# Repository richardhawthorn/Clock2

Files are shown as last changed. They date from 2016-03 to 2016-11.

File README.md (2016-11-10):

### Description

PCB and Arduino code for a basic clock

### Features

- 4 character 7-segment LED display
- ATMEGA328P with Arduino boot-loader
- 5V operation @ 16Mhz
- DS1307 battery backed clock
- 2x buttons to update minutes and seconds
- Mini USB power connector
- FTDI programming port
- Completely through hole design

### License

This work is licensed under a Creative Commons Attribution-ShareAlike 4.0 International License.

<br />
Designed by <a xmlns:cc="http://creativecommons.org/ns#" href="http://www.richardhawthorn.com" property="cc:attributionName" rel="cc:attributionURL" target="_blank">Richard Hawthorn</a><br />
<a rel="license" href="http://creativecommons.org/licenses/by-sa/4.0/" target="_blank">View License</a>

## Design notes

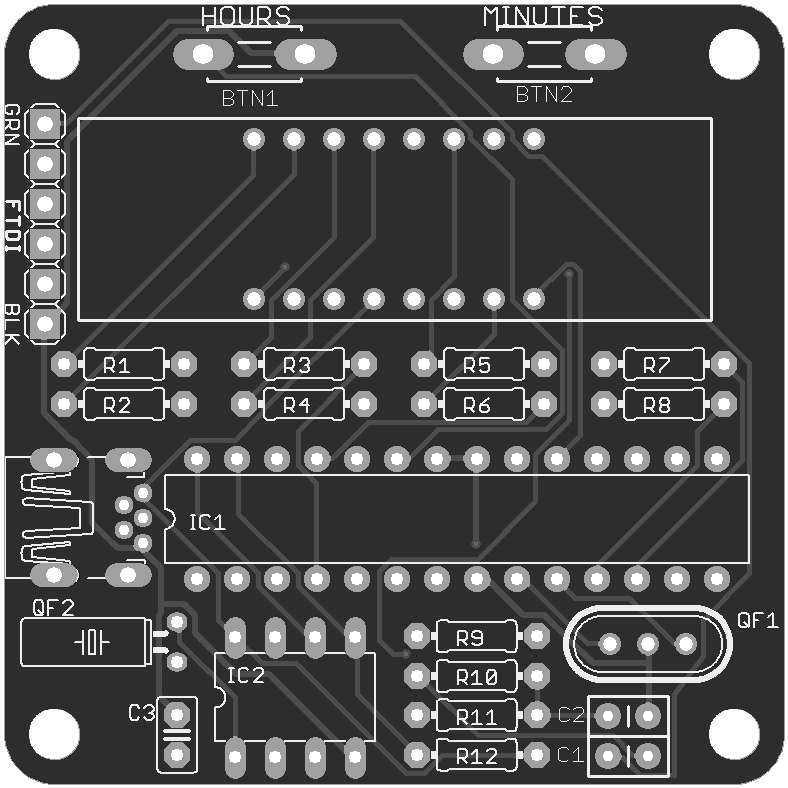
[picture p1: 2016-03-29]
images/pcb_front.png

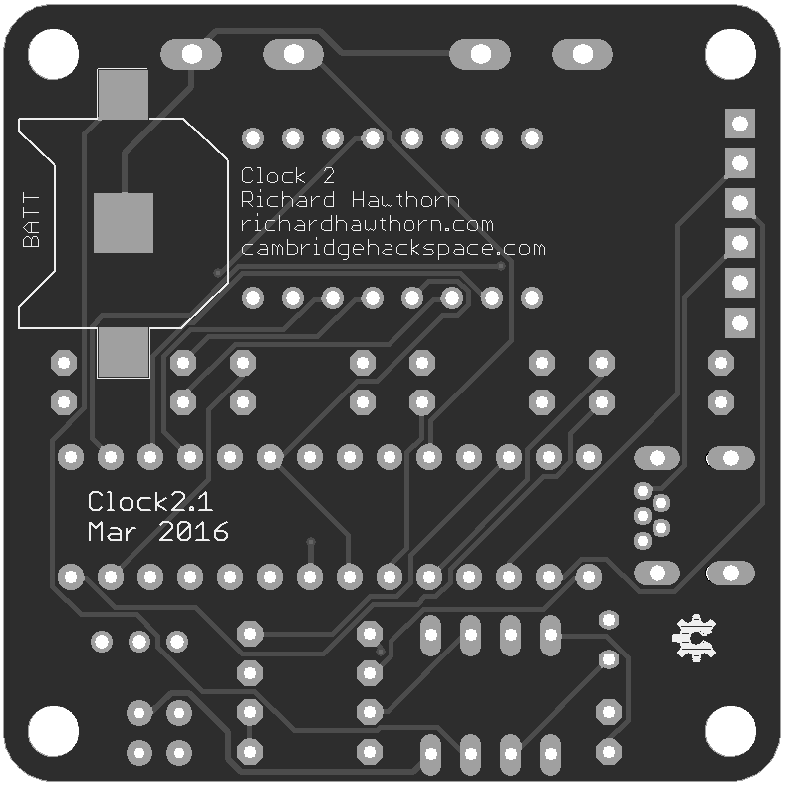
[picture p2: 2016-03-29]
images/pcb_back.png

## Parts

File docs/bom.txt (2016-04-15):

Qty Value       Device                       Package                   Parts                              Description                                    
2   0.1uf       CAP                          CAP-PTH-SMALL             C1, C2, C3                         Capacitor                                                                                                         
3   10K         Resistor                     0204/7                    R10, R11, R12                      Resistor                                                
1   32.768      CRYTALTC38H                  TC38H                     QF2                                Crystal                                                                   
1   7SEG-4DIGIT 7SEG-4DIGIT                  7-SEGMENT-4DIGIT          LED1                               7 Segment LED                                                                          
9   82r         Resistor                     0204/7                    R1, R2, R3, R4, R5, R6, R7, R8, R9 Resistor                                               
1   16Mhz	 16Mhz Crystal                HC49U                     QF1                                Crystal                      
1   ATMEGA328P  ATMEGA328P                   DIL28-3-ROUND             IC1                                Microcontroller                                                           
1   CR1220      CR1220SMT                    CR1220-SMD                BATT                               Battery clip                            
1   DS1307      DS1307                       DIL08                     IC2                                Calendar                                                                    
1   FTDI        PINHD-1X6                    1X06                      CN4                                Pin Header                                                                
1   HOURS       DTS-3                        DTS-3                     BTN1                               Button                                                                          
1   MINUTES     DTS-3                        DTS-3                     BTN2                               Button                                                                          
1   USB         MINI-USB		       32005-601                 X1                                 USB socket

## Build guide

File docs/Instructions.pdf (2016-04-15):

Cambridge Hackspace

# Arduino Clock Assembly Instructions

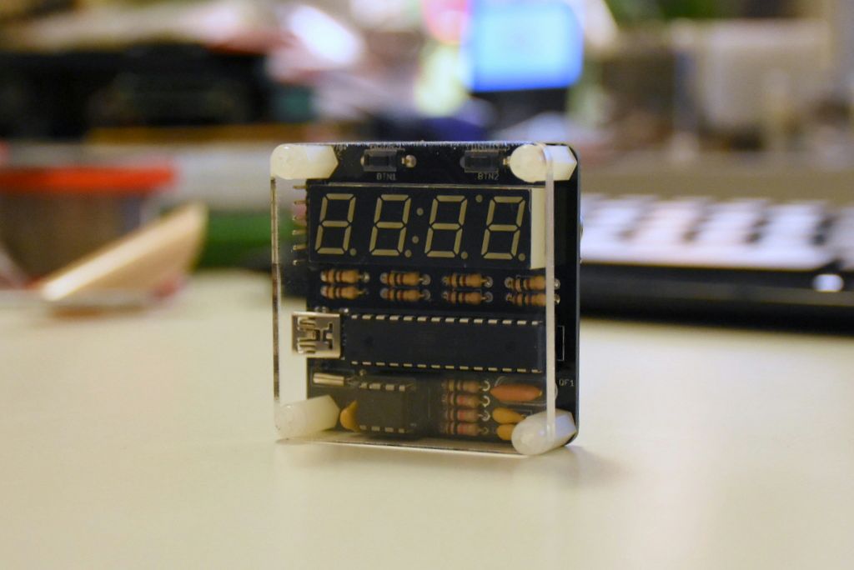
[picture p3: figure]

## Specifications

- 4 character 7-segment LED display
- ATMEGA328P with Arduino boot-loader
- 5V operation @ 16Mhz
- DS1307 battery backed clock
- 2x buttons to update minutes and seconds
- Mini USB power connector
- FTDI programming port

Cambridge Hackspace - Clock2.1

## Parts List

Part # | Qty | Value | Device | Parts
1 | 9 | 82r | Resistor | R1, R2, R3, R4, R5, R6, R7, R8, R9
2 | 3 | 10K | Resistor | R10, R11, R12
3 | 3 | 0.1uf | Capacitor | C1, C2, C3
4 | 1 | DIL28 | 28 pin IC socket | IC1
5 | 1 | ATMEGA328P | Processor | IC1
6 | 1 | DIL8 | 8 pin IC socket | IC2
7 | 1 | DS1307 | Calendar chip | IC2
8 | 1 | 16Mhz | Processor crystal | QF1
9 | 1 | 32.768khz | Calendar crystal | QF2
10 | 1 | 7SEG-4DIGIT | 7 segment LED | LED1
11 | 1 | CR1220 | Battery clip | BATT
12 | 1 | CR1220 | 3V battery | BATT
13 | 1 | USB | Mini USB socket | X1
14 | 1 | FTDI | Pin header | CN4
15 | 1 | HOURS | Button | BTN1
16 | 1 | MINUTES | Button | BTN2
17 | 1 | n/a | PCB | Clock2.1
18 | 1 | n/a | Acrylic front plate | n/a
19 | 4 | n/a | Acrylic pillars | n/a
20 | 8 | n/a | Acrylic screws | n/a
21 | 1 | n/a | Mini USB cable | n/a

## Parts

The kit is supplied with everything you will need to make your Arduino clock.

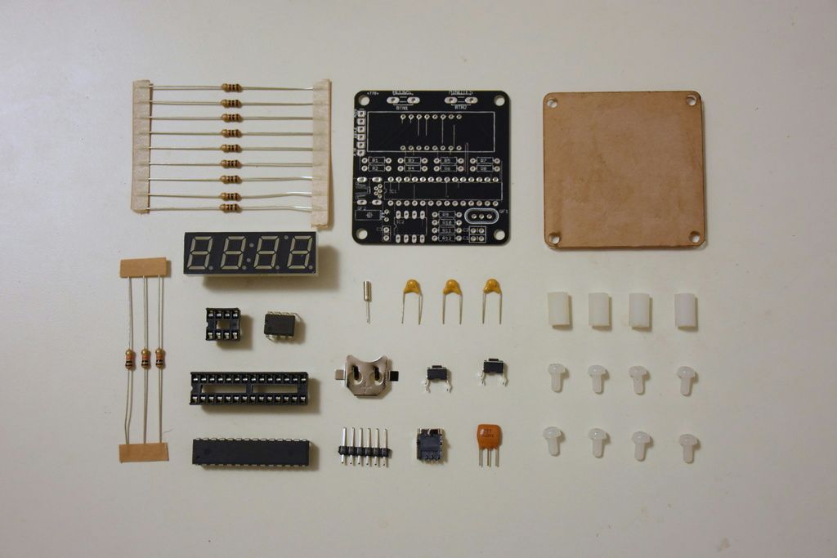
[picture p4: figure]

Other items needed

You will also need a few other items, if you don’t have these at home, you can come into Cambridge Hackspace and borrow ours.
- Soldering iron
- Solder
- Screwdriver
- Wire cutters
- Multimeter
- 5v FTDI Programmer
- Computer for programming
- Power supply from old phone or tablet with USB power out (optional)

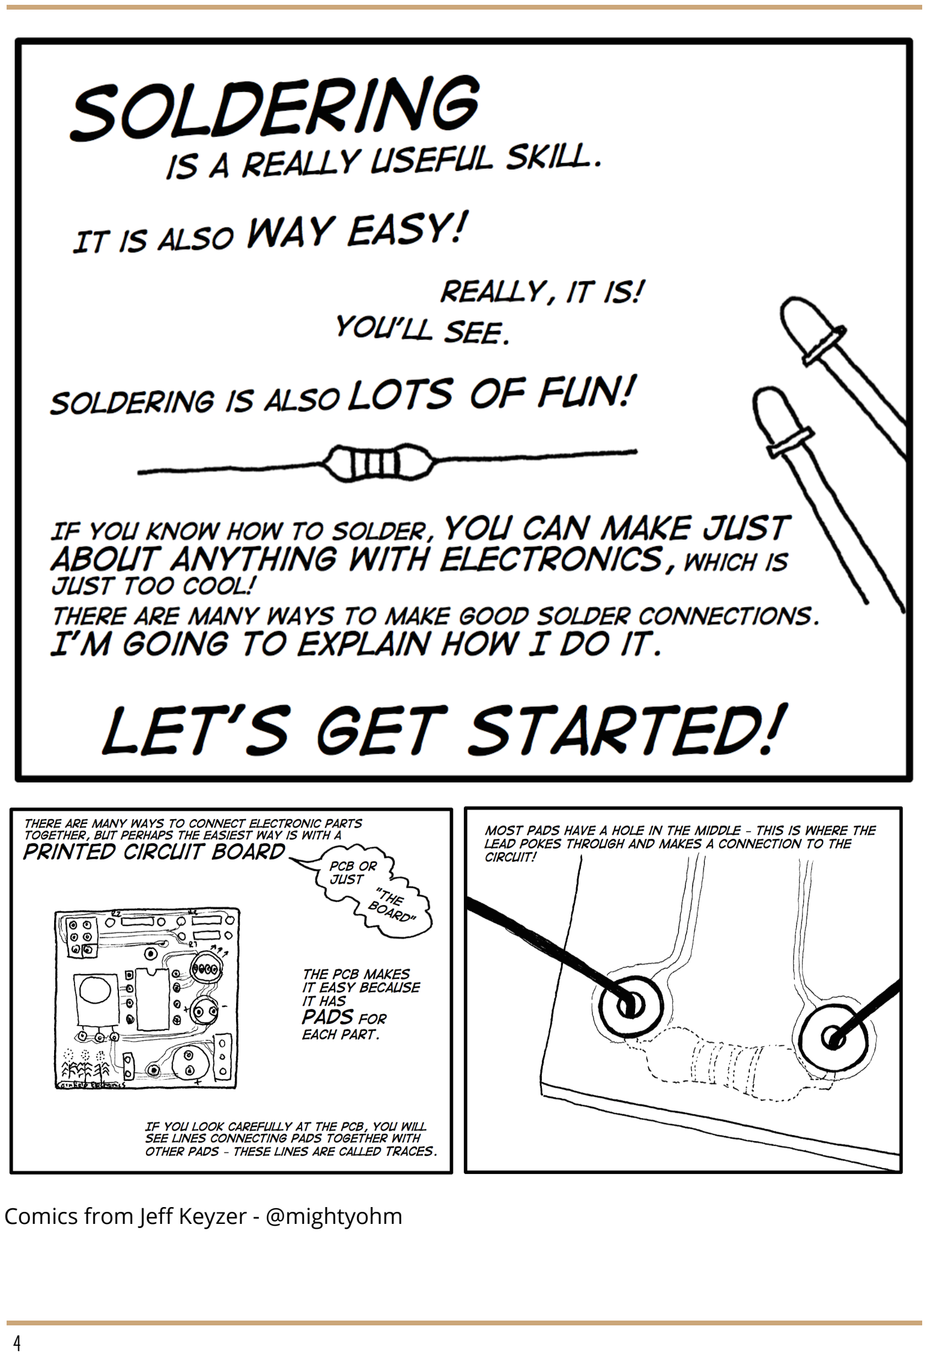
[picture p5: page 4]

Comics from Jeff Keyzer - @mightyohm

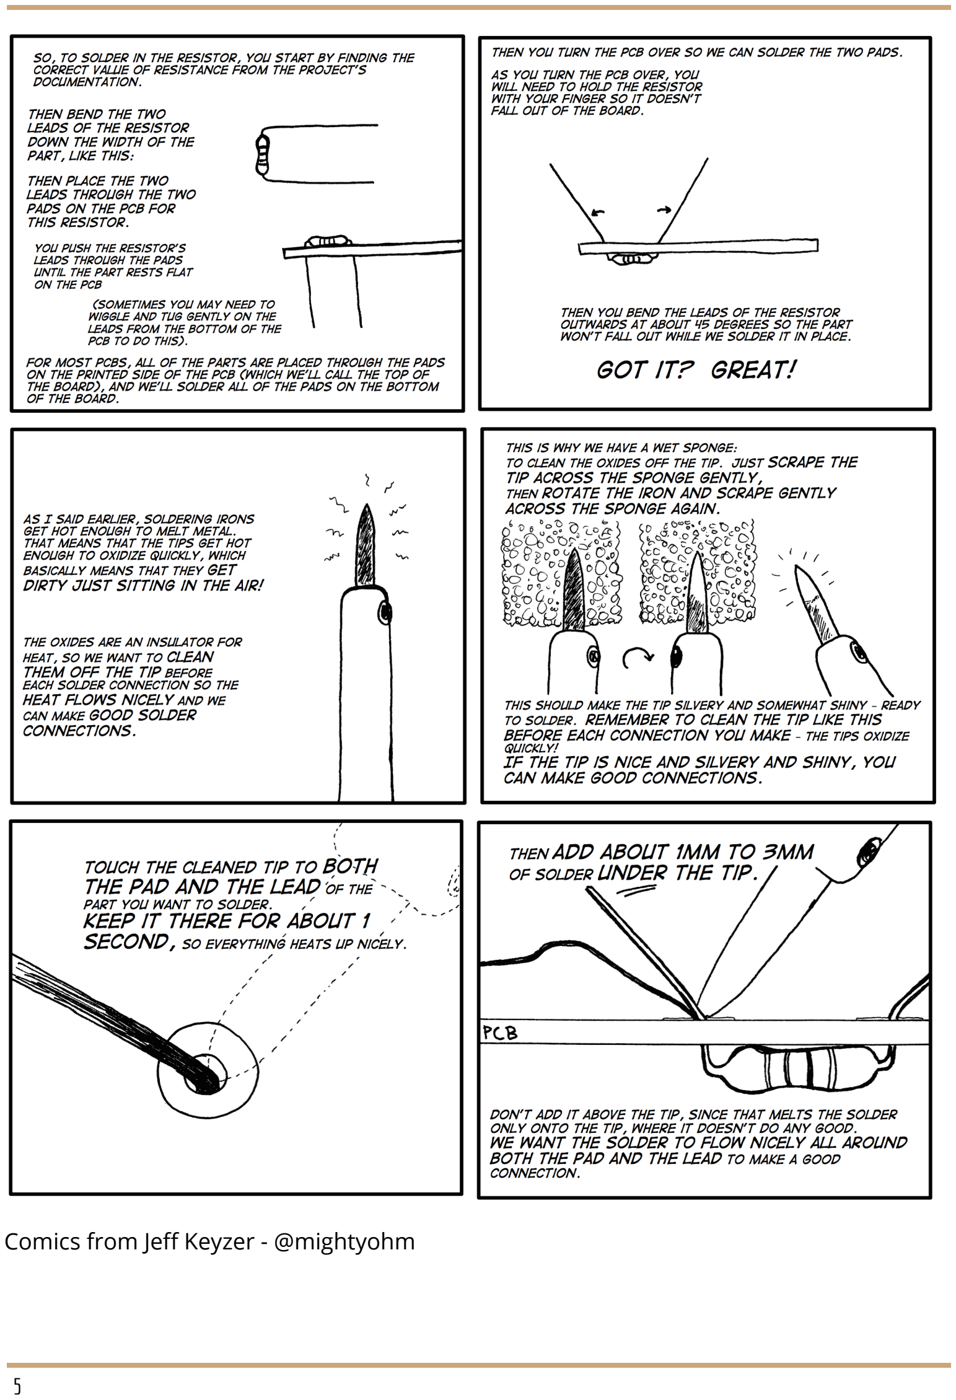
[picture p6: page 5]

Comics from Jeff Keyzer - @mightyohm

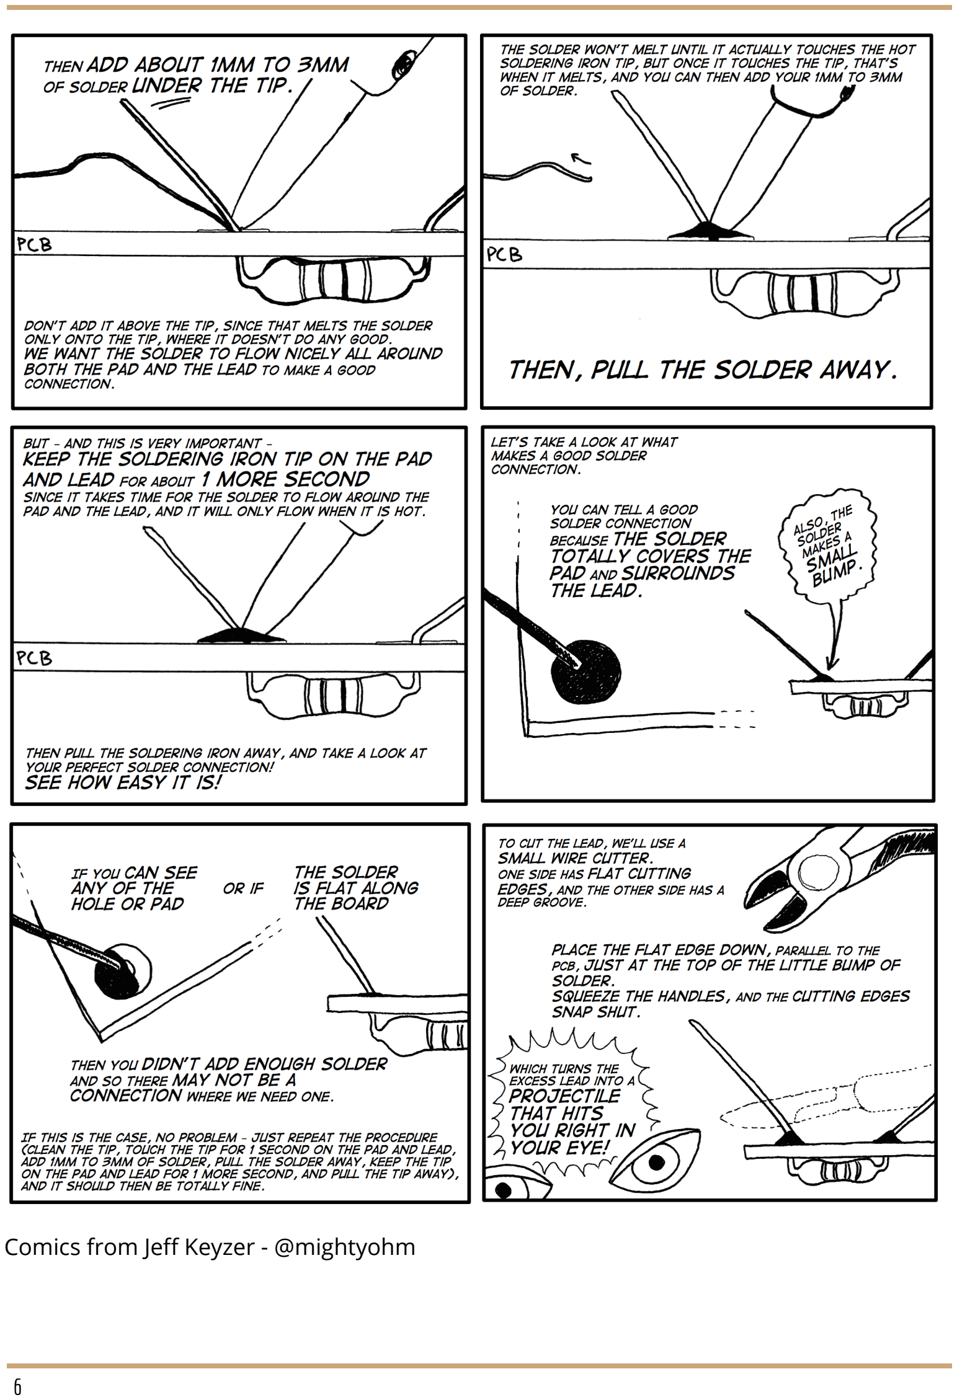
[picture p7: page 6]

Comics from Jeff Keyzer - @mightyohm

## Assembly

We’ll start with the shortest components first, building up to the taller ones. We do this so that the short ones don’t fall out when you’re soldering the tall ones.

This will become clear as you start to solder, especially if you forget a short one, and have to go back to add it in later.

For each component look for the part number on the table, and match it up with the part number on the board.

Below you can see that we are using part QF2, so look for that marking on the PCB.

When a component has multiple pins, it’s a good idea to start by soldering just 2 of those pins first, checking that everything looks good on the front before proceeding. If you notice that the component is on at an angle, or not flush against the back of the PCB, then you can adjust easily before soldering the rest of the pins.

Let’s get started!

Calendar crystal

Part # | Qty | Value | Device | Parts
9 | 1 | 32.768khz | Calendar crystal | QF2

As the calendar crystal is the shortest component we’ll start with it.

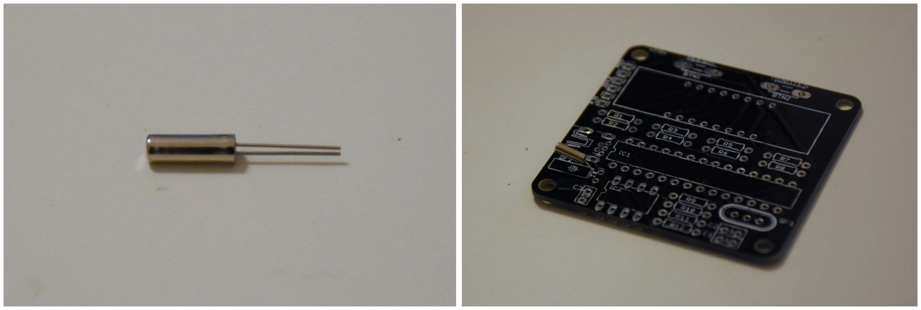
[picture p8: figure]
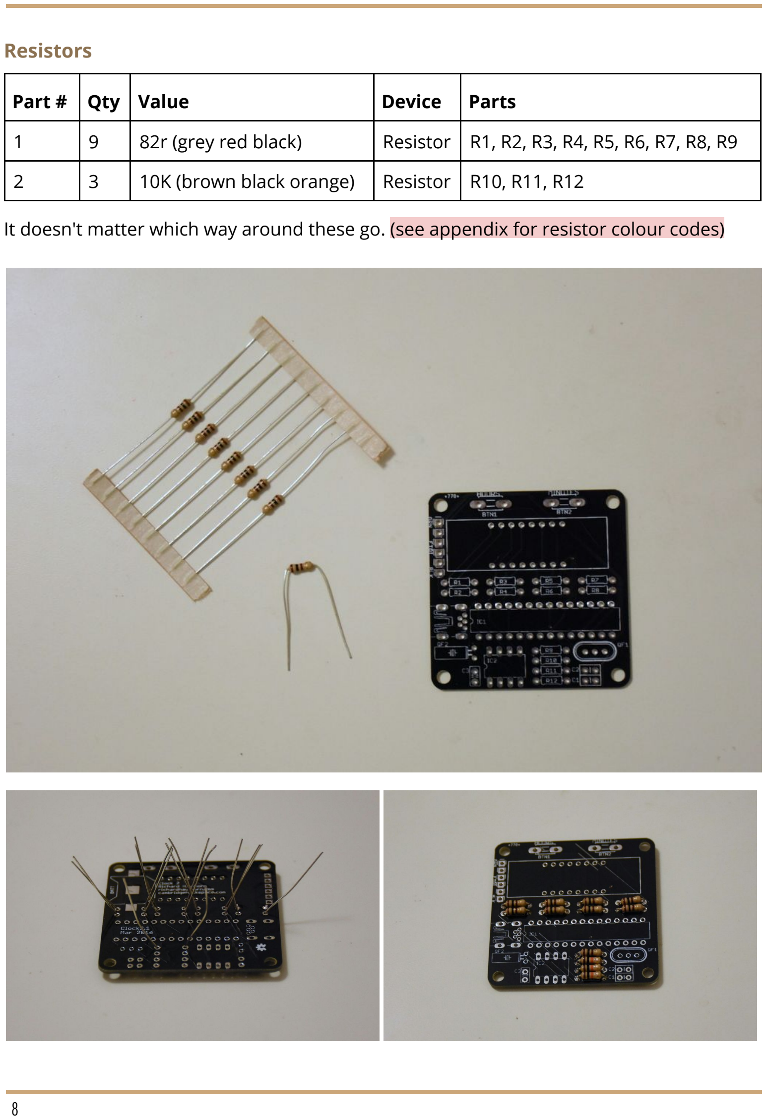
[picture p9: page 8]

Resistors

Part # | Qty | Value | Device | Parts
1 | 9 | 82r (grey red black) | Resistor | R1, R2, R3, R4, R5, R6, R7, R8, R9
2 | 3 | 10K (brown black orange) | Resistor | R10, R11, R12

It doesn't matter which way around these go. (see appendix for resistor colour codes)

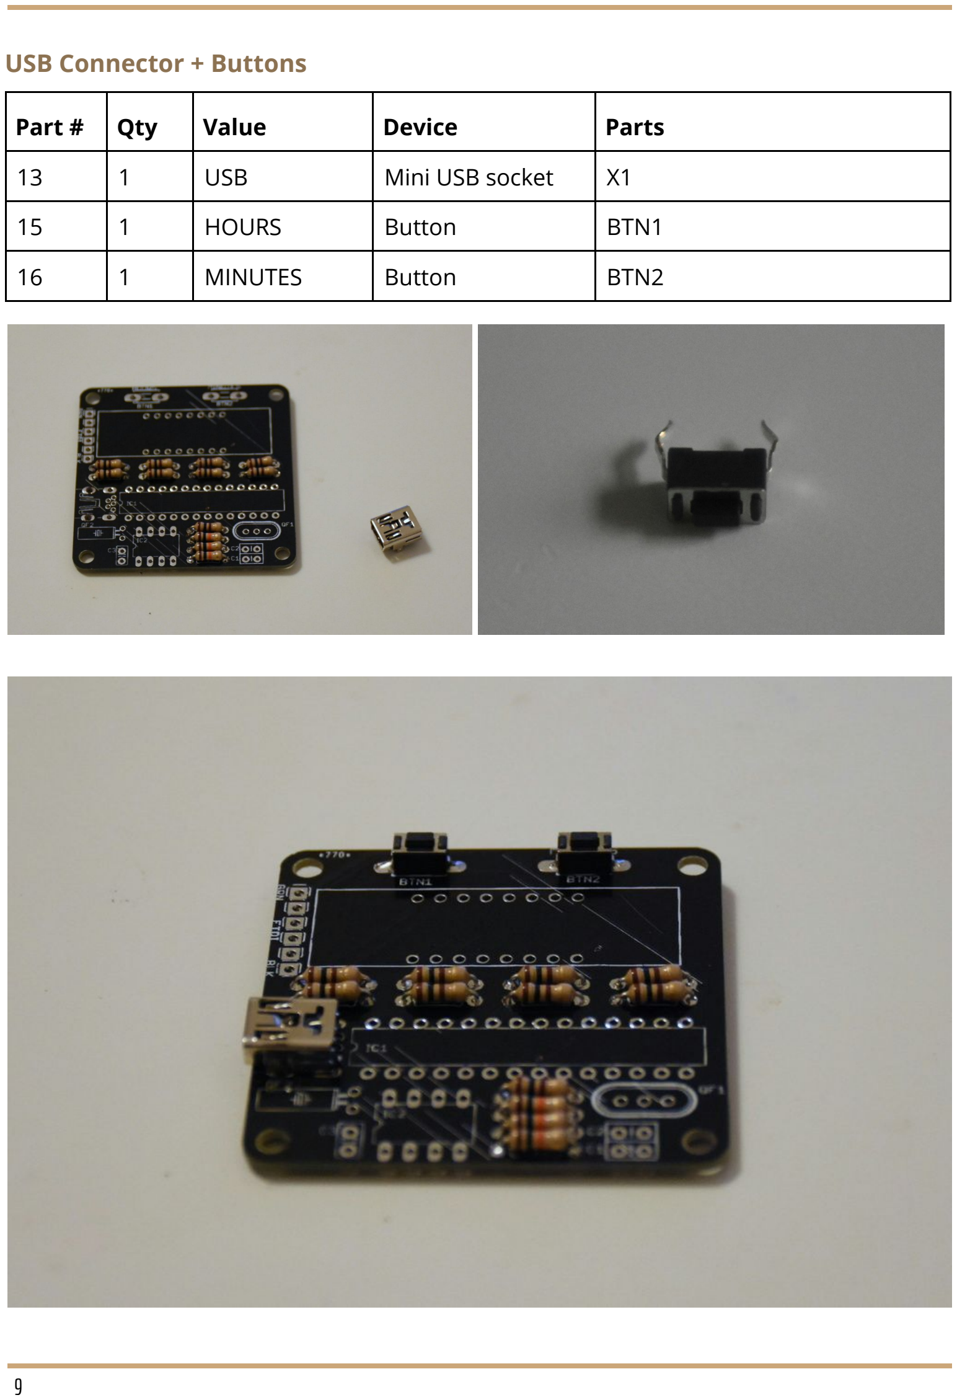
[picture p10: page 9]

USB Connector + Buttons

Part # | Qty | Value | Device | Parts
13 | 1 | USB | Mini USB socket | X1
15 | 1 | HOURS | Button | BTN1
16 | 1 | MINUTES | Button | BTN2

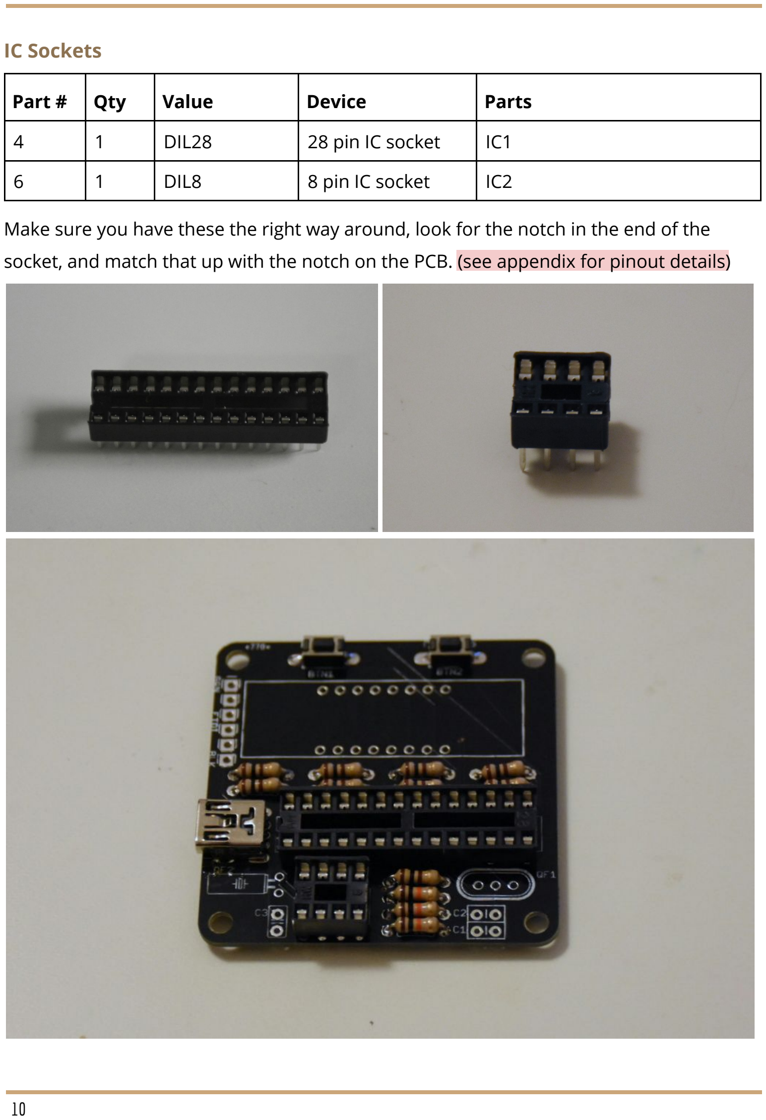
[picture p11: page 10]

IC Sockets

Part # | Qty | Value | Device | Parts
4 | 1 | DIL28 | 28 pin IC socket | IC1
6 | 1 | DIL8 | 8 pin IC socket | IC2

Make sure you have these the right way around, look for the notch in the end of the socket, and match that up with the notch on the PCB. (see appendix for pinout details)

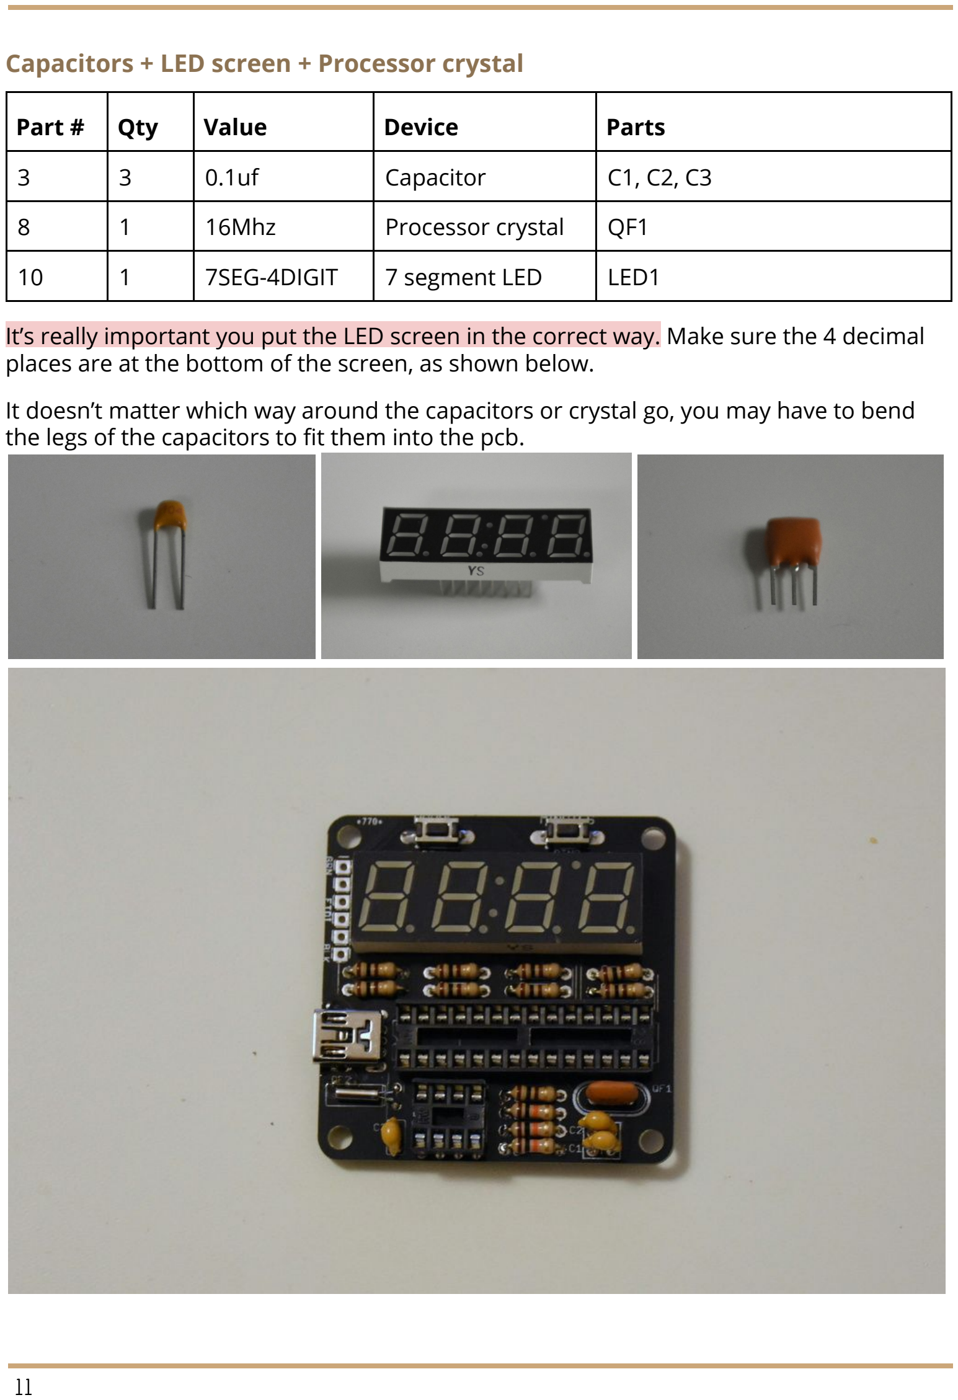
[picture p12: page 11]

Capacitors + LED screen + Processor crystal

Part # | Qty | Value | Device | Parts
3 | 3 | 0.1uf | Capacitor | C1, C2, C3
8 | 1 | 16Mhz | Processor crystal | QF1
10 | 1 | 7SEG-4DIGIT | 7 segment LED | LED1

It’s really important you put the LED screen in the correct way. Make sure the 4 decimal places are at the bottom of the screen, as shown below.
It doesn’t matter which way around the capacitors or crystal go, you may have to bend the legs of the capacitors to fit them into the pcb.

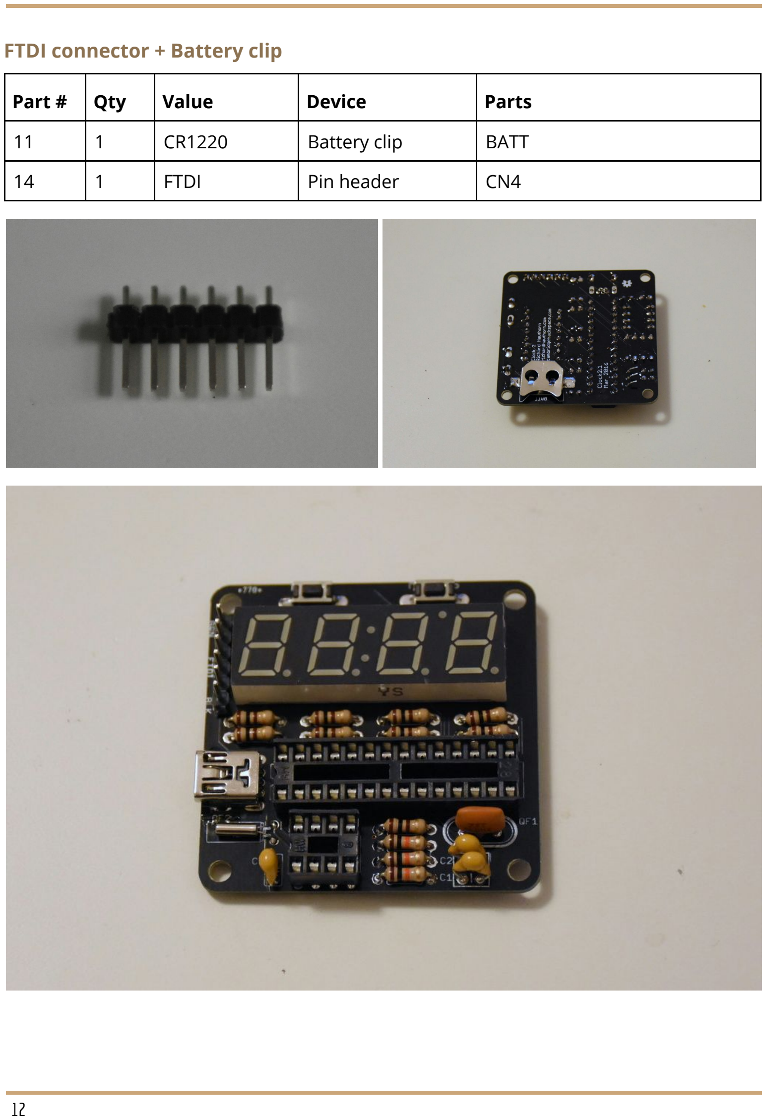
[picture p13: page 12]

FTDI connector + Battery clip

Part # | Qty | Value | Device | Parts
11 | 1 | CR1220 | Battery clip | BATT
14 | 1 | FTDI | Pin header | CN4

Testing
Now is a good time to test your soldering
If you have already added your Arduino and calendar chips, then take them out now. With your multimeter set to continuity mode, test to make sure you don’t have a short on the power line. Try testing the processor pins 7 and 8, they should not be connected.
If you have a short here, or any other unexpected result during this build you will need to investigate further. Check your soldering to make sure pins are not shorted together, make sure all solder joints are clean.
Plug in your USB cable, and check the power on the board, do you get 5v between pins 7 and 8 on the processor?
If you read anything less than 5v, unplug immediately.
If that all looks good then we can add our IC’s.
Unplug the USB power connector before proceeding
Make sure the notch on the end of the ICs matches up with the notch on the socket.

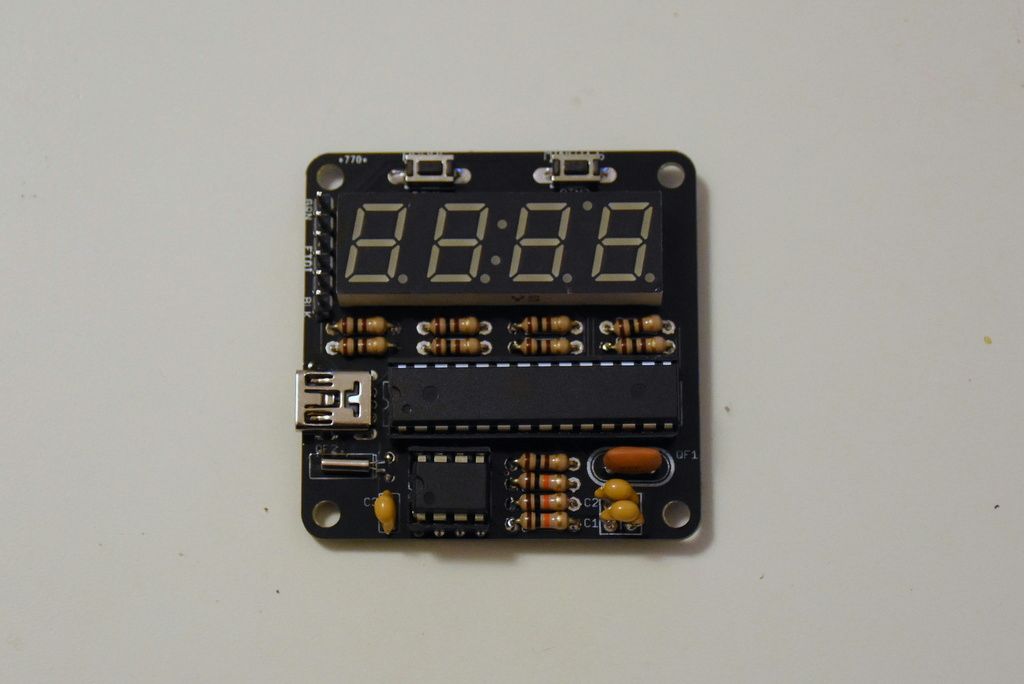
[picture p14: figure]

Programming
You are now ready to program your device, grab an FTDI programmer, your USB cable and your laptop.
Make sure you have downloaded the Arduino IDE from arduino.cc
You will also need the RTC library,
Download the library from here, using the ‘download zip’ button https://github.com/adafruit/RTClib
Unpack the folder, and make sure you remove the ‘-master’ from the folder name Copy this into your Arduino Library folder, this will probably be located at arduinosketchfolder/libraries/
Restart the Arduino IDE
You can now download the clock software here: https://github.com/richardhawthorn/Clock1
When programming set the device as “Arduino UNO”
Connect the FTDI programmer to your clock, make sure that the ‘blk’ and ‘grn’ markings match up on the PCB and FTDI programmer.
You can now program the chip.
Now is a good time to add in your battery
Potential Issues
Problem | Solution
Arduino does not program | Make sure the Arduino is powered correctly when the programmer is connected, check solder joints on the arduino chip. Make sure the FTDI connectors is on the right way.
Not all segments light up | Check your soldering on the Arduino chip and 7 segment screen
Display shows 6500 | Make sure the calendar chip is in correctly, and that the battery has been added.

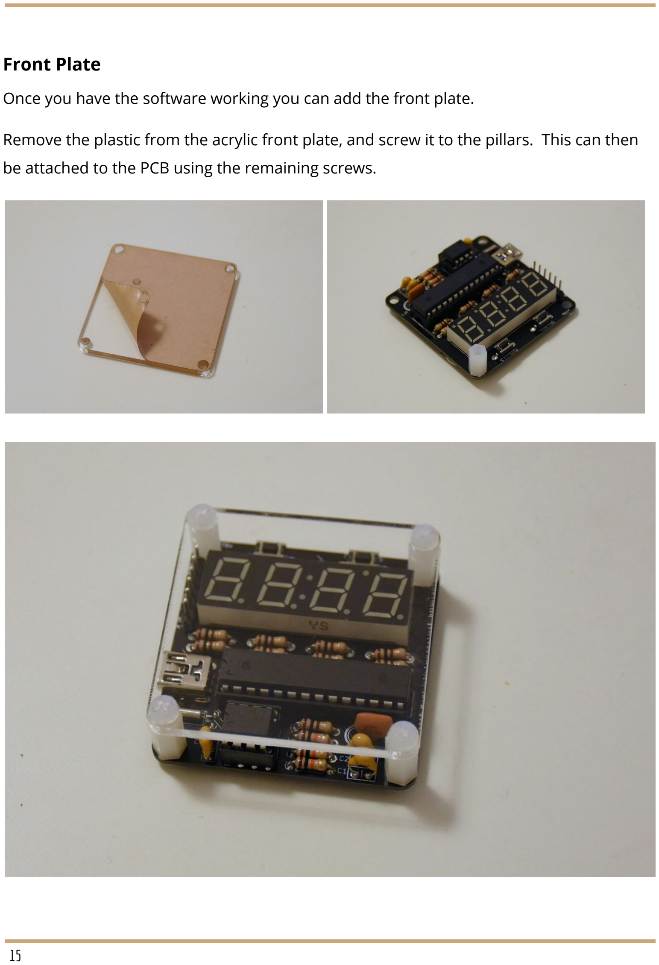
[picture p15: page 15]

Front Plate
Once you have the software working you can add the front plate.

Remove the plastic from the acrylic front plate, and screw it to the pillars. This can then be attached to the PCB using the remaining screws.

Appendix
General component information

You need to make sure you add your ICs in the right way around, they will have a notch at one end, this will let you know which way around they go. You can identify pins by counting anti clockwise from the notch.

Resistor Values

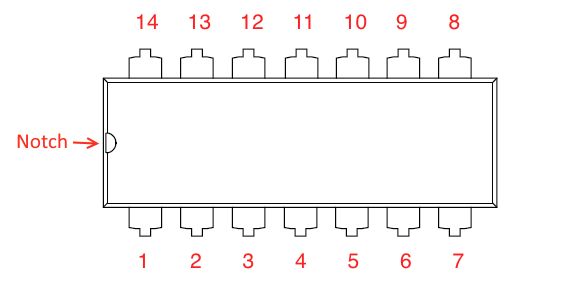
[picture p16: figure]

Resistors can be read by looking at their colour code, using the following table.

Colour | 1st Band | 2nd Band | 3rd Band | Multiplier | Tolerance
Black | 0 | 0 | 0 | 1Ω
Brown | 1 | 1 | 1 | 10Ω | ±1%
Red | 2 | 2 | 2 | 100Ω | ±2%
Orange | 3 | 3 | 3 | 1kΩ
Yellow | 4 | 4 | 4 | 10kΩ
Green | 5 | 5 | 5 | 100kΩ | ±0.5%
Blue | 6 | 6 | 6 | 1MΩ | ±0.25%
Violet | 7 | 7 | 7 | 10MΩ | ±0.1%
Grey | 8 | 8 | 8 | n/a | ±0.05%
White | 9 | 9 | 9 | n/a
Gold | | | | 0.1Ω | ±5%
Silver | | | | 0.01Ω | ±10%

Credits
Designed, tested, and documented by Richard Hawthorn

www.richardhawthorn.com
@richardhawthorn

Soldering comics
Soldering comic excerpts from Jeff Keyzer - @mightyohm

http://mightyohm.com/blog/2011/04/soldering-is-easy-comic-book/

Workshop
Run as a workshop at Cambridge Hackspace www.cambridgehackspace.com

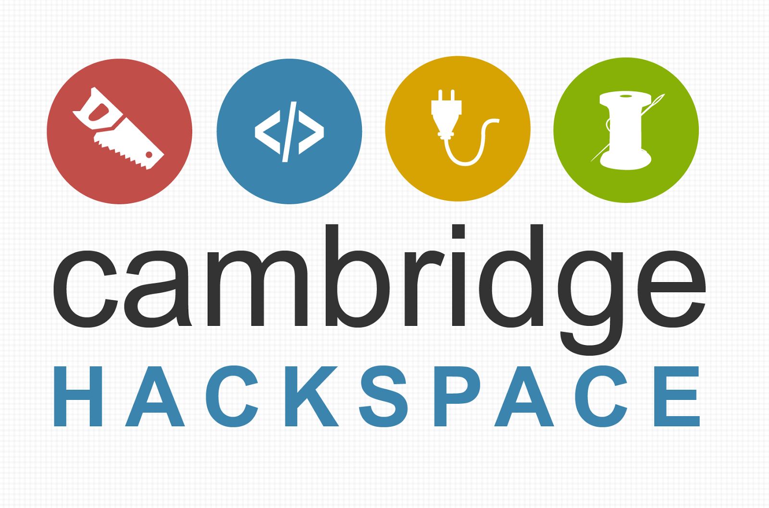
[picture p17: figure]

Licence
Released under a Creative Commons license (Attribution-ShareAlike) (http://creativecommons.org/licenses/by-sa/3.0/us/)

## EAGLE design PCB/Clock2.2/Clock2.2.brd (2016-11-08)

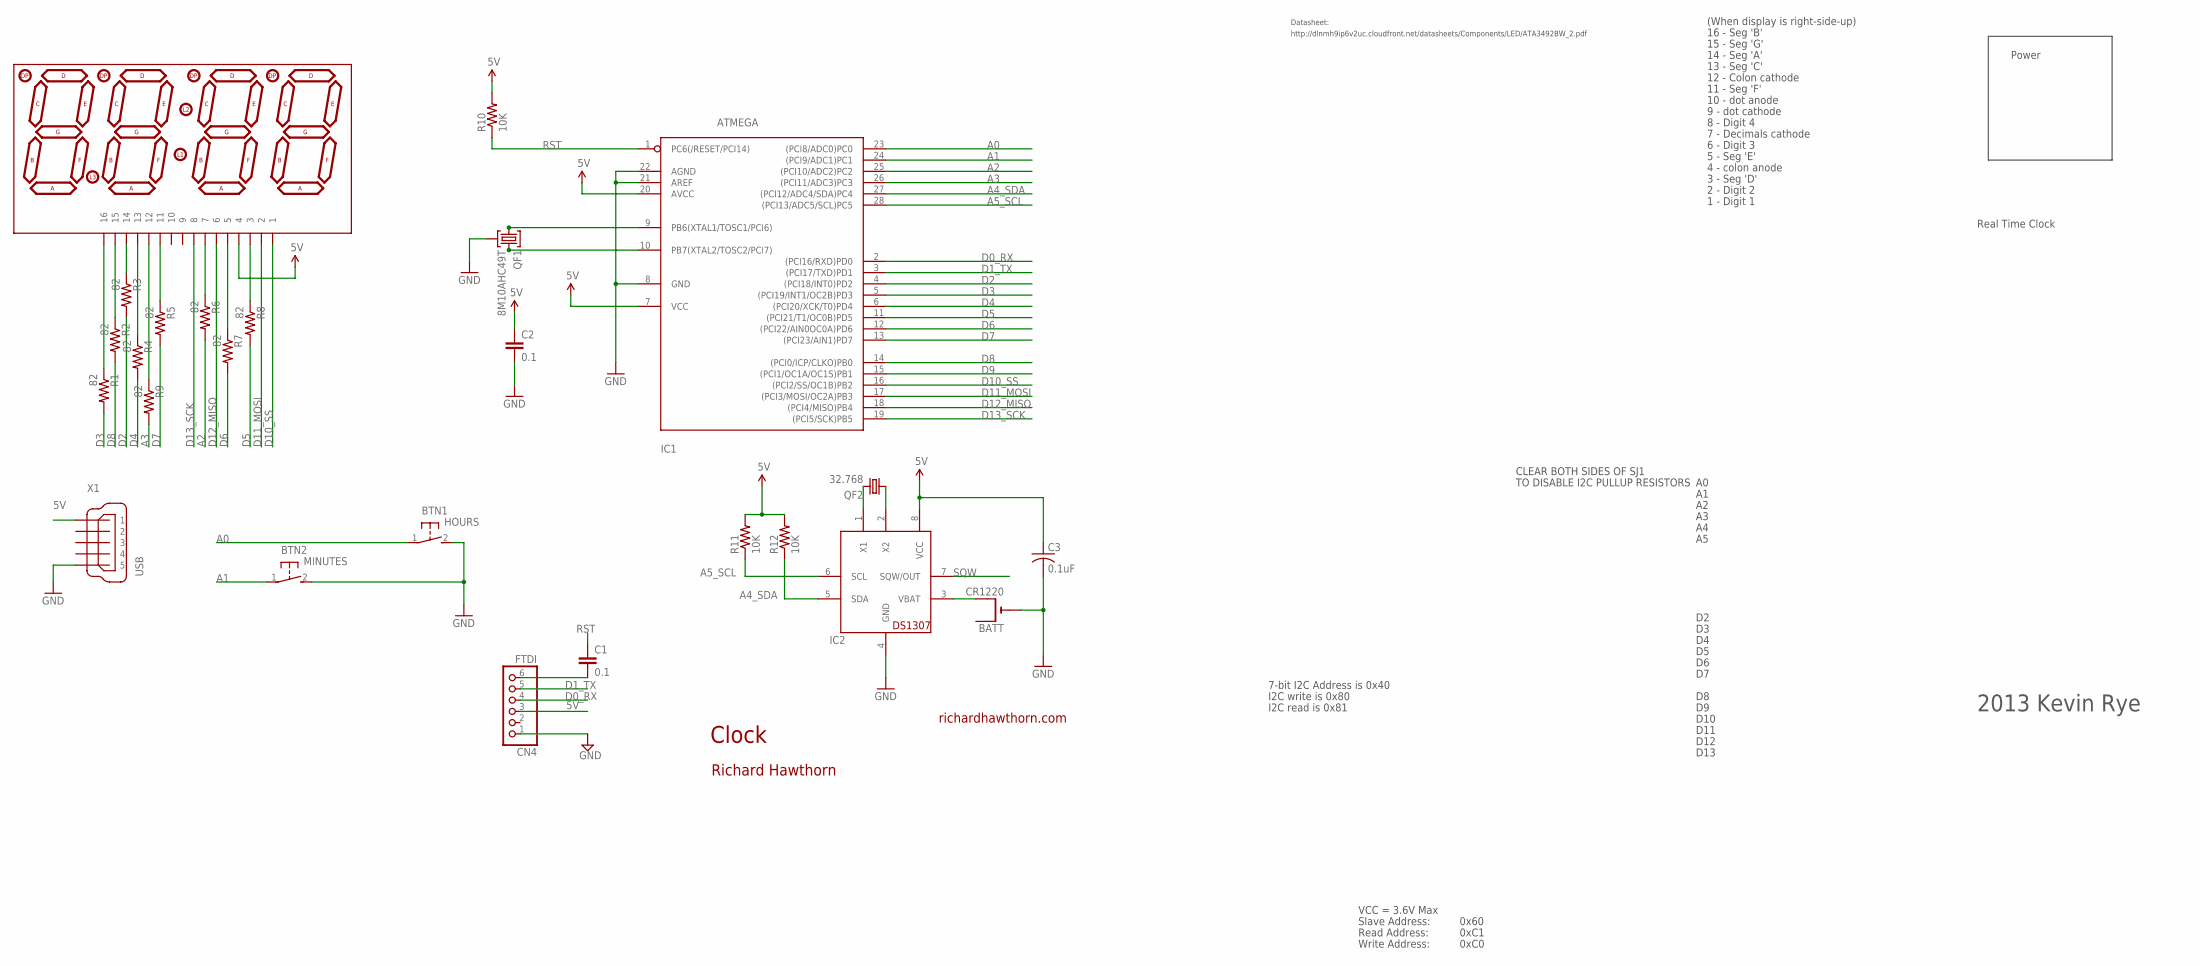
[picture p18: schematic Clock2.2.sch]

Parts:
BATT: CR1220; CR1220-SMD
BTN1: HOURS; DTS-3
BTN2: MINUTES; DTS-3
C1, C2: 0.1; CAP-PTH-SMALL2
C3: 0.1uF; C025-025X050
CN4: FTDI; 1X06
IC1: ATMEGA; DIL28-3-ROUND
IC2: DS1307; DIL08
LED1: 7SEG-4DIGIT; SPARKFUN_7-SEGMENT-4DIGIT
QF1: 8M10AHC49T; HC49U
QF2: 32.768; TC38H
R1, R2, R3, R4, R5, R6, R7, R8, R9: 82; 0204/7
R10, R11, R12: 10K; 0204/7
X1: USB; 32005-601

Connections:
5V: C2.1, C3.1, CN4.3, IC1.7 (VCC), IC1.20 (AVCC), IC2.8 (VCC), LED1.4, R10.2, R11.2, R12.2, X1.1
A0: BTN1.1, IC1.23 ((PCI8/ADC0)PC0)
A1: BTN2.1, IC1.24 ((PCI9/ADC1)PC1)
A2: IC1.25 ((PCI10/ADC2)PC2), R6.2
A3: IC1.26 ((PCI11/ADC3)PC3), R9.2
A4_SDA: IC1.27 ((PCI12/ADC4/SDA)PC4), IC2.5 (SDA), R12.1
A5_SCL: IC1.28 ((PCI13/ADC5/SCL)PC5), IC2.6 (SCL), R11.1
D0_RX: CN4.4, IC1.2 ((PCI16/RXD)PD0)
D1_TX: CN4.5, IC1.3 ((PCI17/TXD)PD1)
D2: IC1.4 ((PCI18/INT0)PD2), R3.2
D3: IC1.5 ((PCI19/INT1/OC2B)PD3), R1.2
D4: IC1.6 ((PCI20/XCK/T0)PD4), R4.2
D5: IC1.11 ((PCI21/T1/OC0B)PD5), R8.2
D6: IC1.12 ((PCI22/AIN0OC0A)PD6), R7.2
D7: IC1.13 ((PCI23/AIN1)PD7), R5.2
D8: IC1.14 ((PCI0/ICP/CLKO)PB0), R2.2
D9: IC1.15 ((PCI1/OC1A/OC1S)PB1)
D10_SS: IC1.16 ((PCI2/SS/OC1B)PB2), LED1.1
D11_MOSI: IC1.17 ((PCI3/MOSI/OC2A)PB3), LED1.2
D12_MISO: IC1.18 ((PCI4/MISO)PB4), LED1.6
D13_SCK: IC1.19 ((PCI5/SCK)PB5), LED1.8
GND: BATT.-, BTN1.2, BTN2.2, C2.2, C3.2, CN4.1, IC1.8 (GND), IC1.21 (AREF), IC1.22 (AGND), IC2.4 (GND), QF1.2, X1.5
unnamed: BATT.+$2 (+1), IC2.3 (VBAT)
unnamed: LED1.16, R1.1
unnamed: LED1.15, R2.1
unnamed: LED1.12, R9.1
unnamed: LED1.7, R6.1
unnamed: IC2.1 (X1), QF2.2
unnamed: IC2.2 (X2), QF2.1
unnamed: IC1.9 (PB6(XTAL1/TOSC1/PCI6)), QF1.1
unnamed: C1.2, CN4.6
unnamed: LED1.13, R4.1
unnamed: LED1.14, R3.1
unnamed: LED1.11, R5.1
unnamed: IC1.10 (PB7(XTAL2/TOSC2/PCI7)), QF1.3
unnamed: LED1.5, R7.1
unnamed: LED1.3, R8.1
RST: C1.1, IC1.1 (PC6(/RESET/PCI14)), R10.1
SQW: IC2.7 (SQW/OUT)

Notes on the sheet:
Clock
richardhawthorn.com
Richard Hawthorn
CLEAR BOTH SIDES OF SJ1
TO DISABLE I2C PULLUP RESISTORS
7-bit I2C Address is 0x40
I2C write is 0x80
I2C read is 0x81
VCC = 3.6V Max
Read Address:
Write Address:
Slave Address:
0x60
0xC1
0xC0
14 - Seg 'A'
13 - Seg 'C'
12 - Colon cathode
11 - Seg 'F'
10 - dot anode
9 - dot cathode
8 - Digit 4
7 - Decimals cathode
6 - Digit 3
5 - Seg 'E'
4 - colon anode
3 - Seg 'D'
2 - Digit 2
Real Time Clock
1 - Digit 1
15 - Seg 'G'
16 - Seg 'B'
D10
D11
D12
D13
http://dlnmh9ip6v2uc.cloudfront.net/datasheets/Components/LED/ATA3492BW_2.pdf
Datasheet:
Power
(When display is right-side-up)

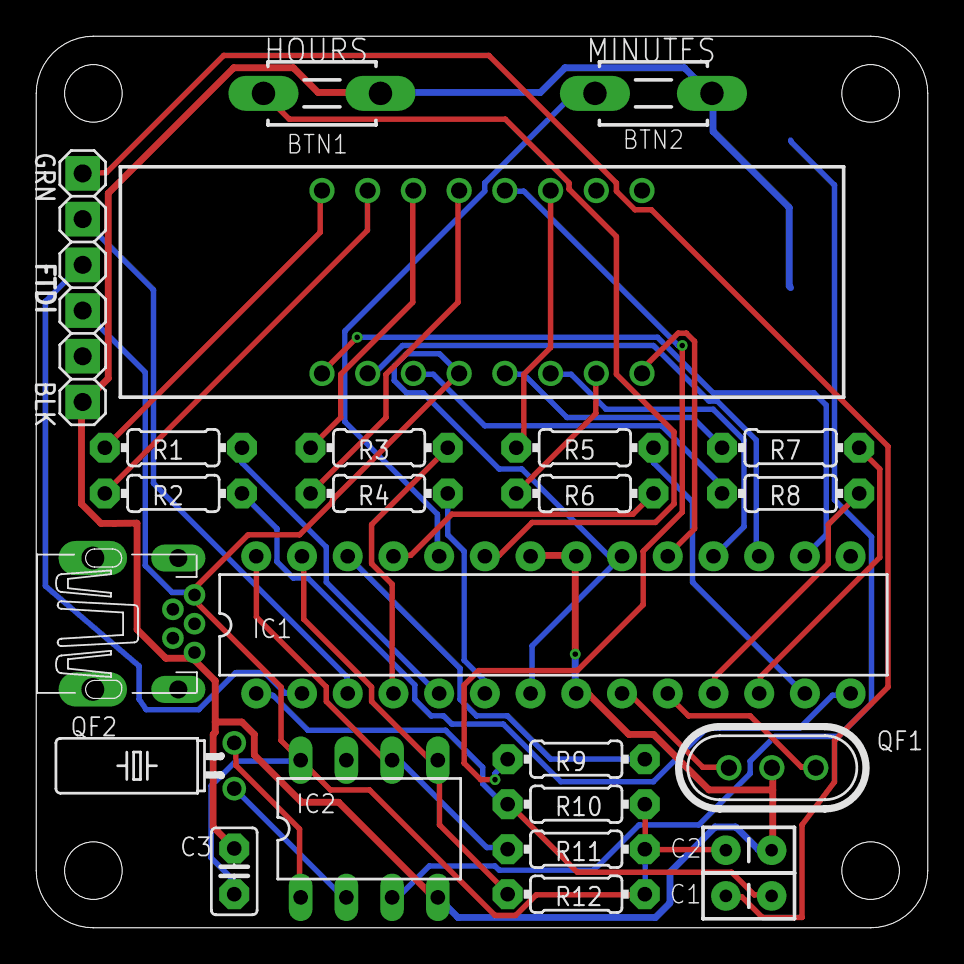
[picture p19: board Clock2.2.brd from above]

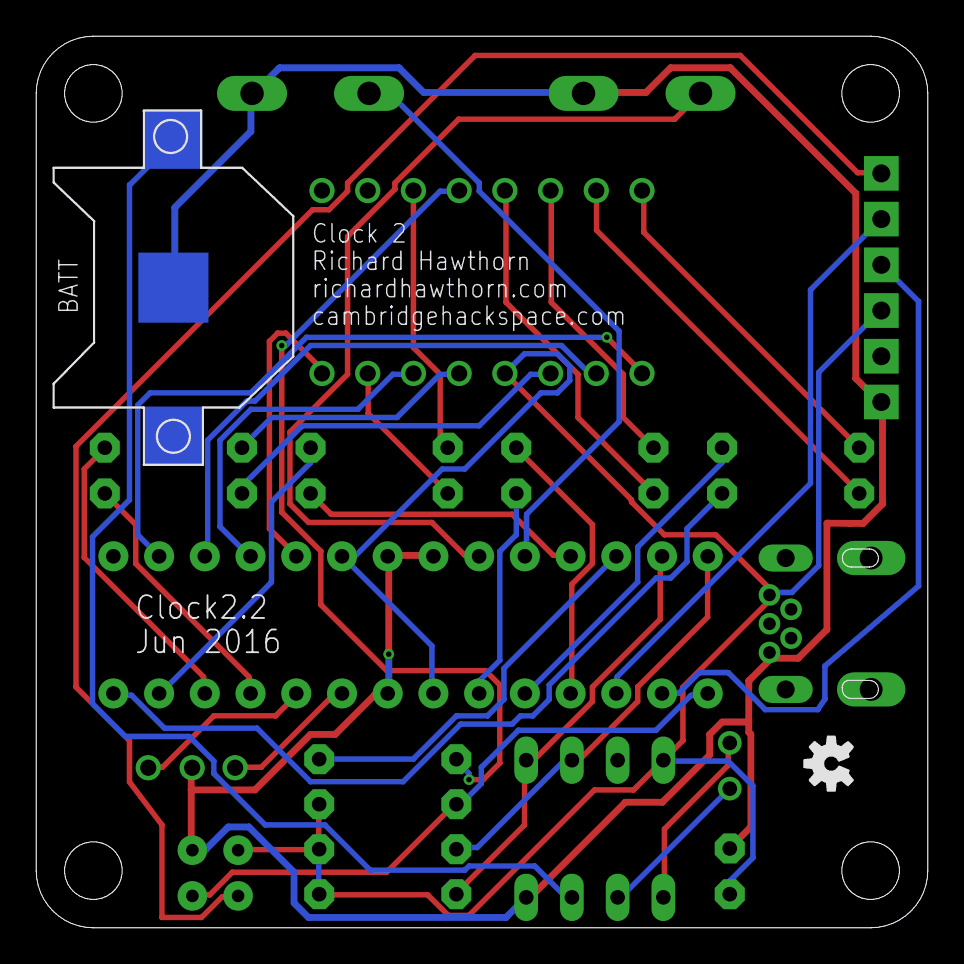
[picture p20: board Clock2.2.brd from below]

Board: 2 copper layers, 49.5 x 49.5 mm, 26 parts (2 on the bottom side), 37 nets.

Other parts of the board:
U$3: OSHW-LOGO-S

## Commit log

2016-03-29 add design files
    [Clock2.1.brd, Clock2.1.sch]
2016-04-15 add bom
2016-11-08 Adding v2 of the pcb
    [Clock2.2.brd, Clock2.2.sch]

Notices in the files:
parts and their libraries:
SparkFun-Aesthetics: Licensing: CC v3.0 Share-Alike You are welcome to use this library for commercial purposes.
